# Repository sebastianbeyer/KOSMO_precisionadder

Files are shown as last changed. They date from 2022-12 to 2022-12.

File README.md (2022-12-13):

Precision adder based on [Doepfer A185-2](https://doepfer.de/a1852.htm) in KOSMO format.

You can use precision opamps, but I found that simple TL074 also work.
I could not get the 1V reference voltage to be exactly 1V, maybe my regulator was not great or my resitors were a bit off. 
I would suggest to use not 100 ohms for that, but maybe 500? 

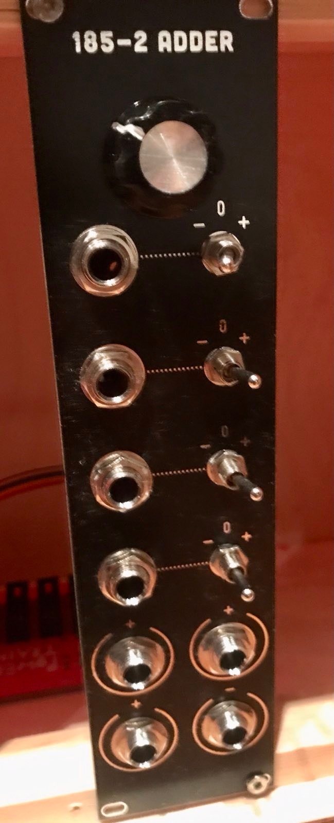
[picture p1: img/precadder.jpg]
Picture of module in case


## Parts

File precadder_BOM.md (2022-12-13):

# precadder.kicad_sch BOM

Tue 13 Dec 2022 10:33:28 CET

Generated from schematic by Eeschema 6.0.8-f2edbf62ab~116~ubuntu22.04.1

**Component Count:** 49

| Refs | Qty | Component | Description | Vendor | SKU |
| ----- | --- | ---- | --- | ---- | ---- |
| C1, C2 | 2 | 10u | Polarized capacitor | Tayda |  |
| C3, C4, C5, C6 | 4 | 100n | Unpolarized capacitor |  |  |
| D1, D2 | 2 | 1N5817 | Schottky Barrier Rectifier Diode, DO-41 | Tayda | A-159 |
| J1 | 1 | out_inv | Audio Jack, 2 Poles (Mono / TS), Switched T Pole (Normalling) | Tayda | A-1121 |
| J2 | 1 | Synth_power_2x5 | Pin header 2.54 mm 2x5 | Tayda | A-2939 |
| J3 | 1 | in_1 | Audio Jack, 2 Poles (Mono / TS), Switched T Pole (Normalling) | Tayda | A-1121 |
| J4 | 1 | in_2 | Audio Jack, 2 Poles (Mono / TS), Switched T Pole (Normalling) | Tayda | A-1121 |
| J5 | 1 | in_3 | Audio Jack, 2 Poles (Mono / TS), Switched T Pole (Normalling) | Tayda | A-1121 |
| J6 | 1 | in_4 | Audio Jack, 2 Poles (Mono / TS), Switched T Pole (Normalling) | Tayda | A-1121 |
| J7 | 1 | out_1 | Audio Jack, 2 Poles (Mono / TS), Switched T Pole (Normalling) | Tayda | A-1121 |
| J8 | 1 | out_3 | Audio Jack, 2 Poles (Mono / TS), Switched T Pole (Normalling) | Tayda | A-1121 |
| J9, J10 | 2 | Conn_01x05_Male | Generic connector, single row, 01x05, script generated (kicad-library-utils/schlib/autogen/connector/) |  |  |
| J11, J12 | 2 | Conn_01x05_Female | Generic connector, single row, 01x05, script generated (kicad-library-utils/schlib/autogen/connector/) |  |  |
| J13 | 1 | out_2 | Audio Jack, 2 Poles (Mono / TS), Switched T Pole (Normalling) | Tayda | A-1121 |
| R1 | 1 | 1k | Resistor | Tayda |  |
| R2, R6, R7, R11, R15, R18 | 6 | 100 | Resistor | Tayda |  |
| R3, R8, R9, R10, R12, R16, R17 | 7 | *100k | Resistor | Tayda |  |
| R4 | 1 | 15k | Resistor | Tayda |  |
| R5 | 1 | 10k | Resistor | Tayda |  |
| R13, R14 | 2 | 100k | Resistor | Tayda |  |
| RV1 | 1 | 100 | Trim-potentiometer | https://www.reichelt.de/praezisionspotentiometer-25-gaenge-stehend-100-ohm-64z-100-p2731.html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 | maybe not 100ohm, but more like 500? |
| RV2 | 1 | gain 500 | Trim-potentiometer | Tayda |  |
| RV3 | 1 | 50k A | Potentiometer | Tayda |  |
| SW1, SW2, SW3, SW4 | 4 | SW_SPDT_MSM | Switch, single pole double throw, center OFF position | Tayda | A-3187 |
| U1, U2 | 2 | LT1014 / TL074 | Quad operational amplifier, DIP-14 | Tayda | A-1138 |
| U3 | 1 | TL431LP | Shunt Regulator, TO-92 |  |  |

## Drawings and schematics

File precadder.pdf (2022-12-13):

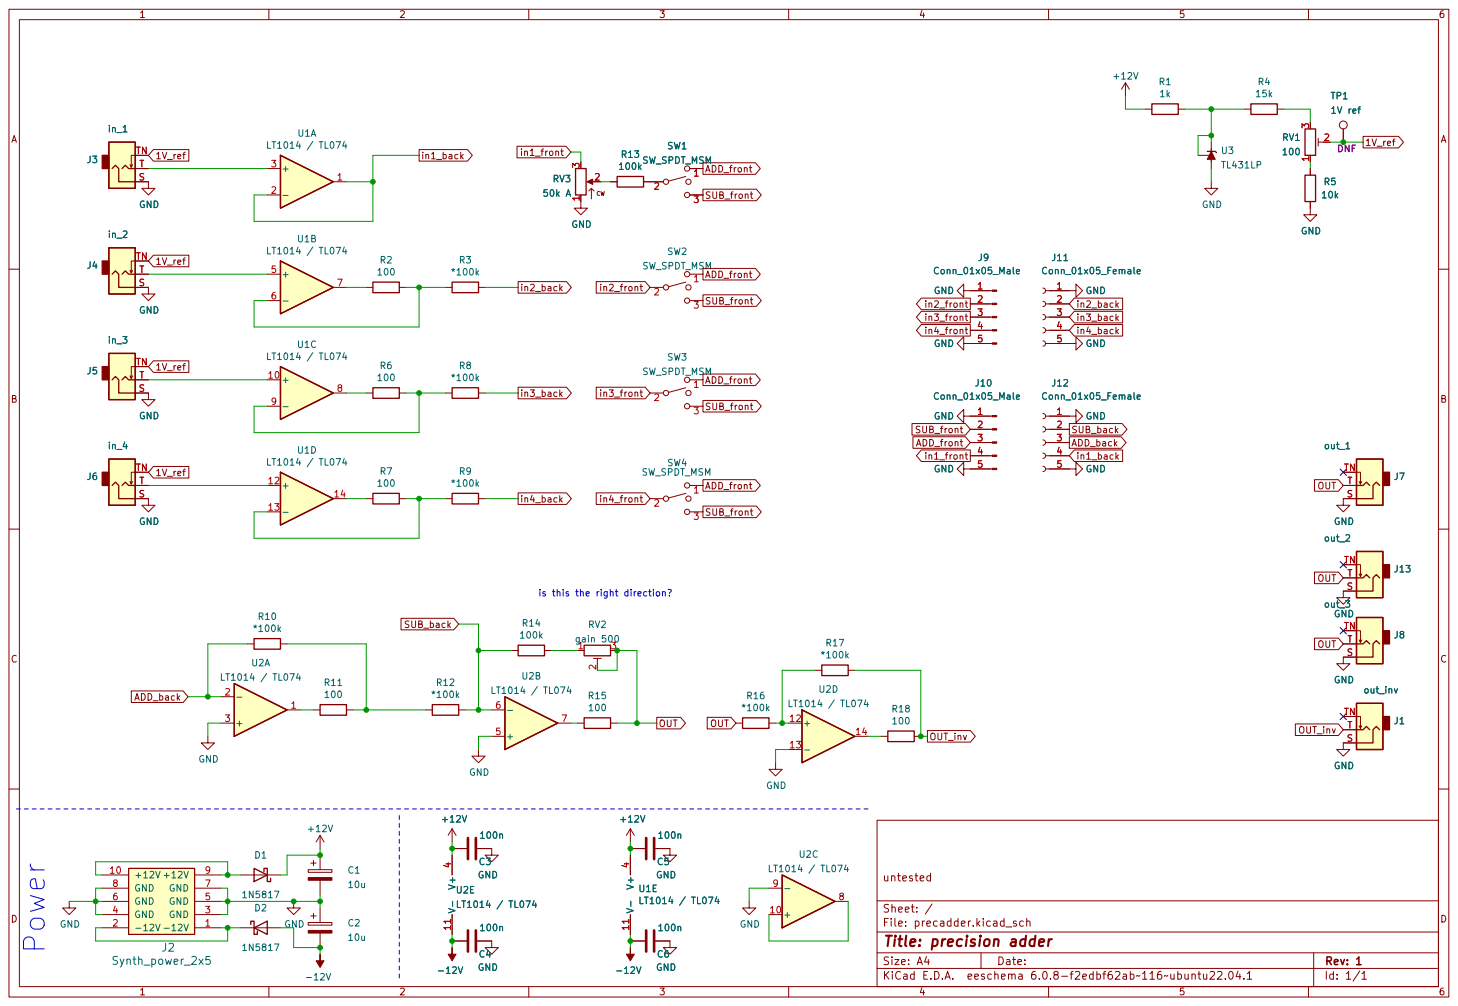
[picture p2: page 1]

is this the right direction? Power

File: precadder.kicad_sch Sheet: / untested

Id: 1/1 Title: precision adder

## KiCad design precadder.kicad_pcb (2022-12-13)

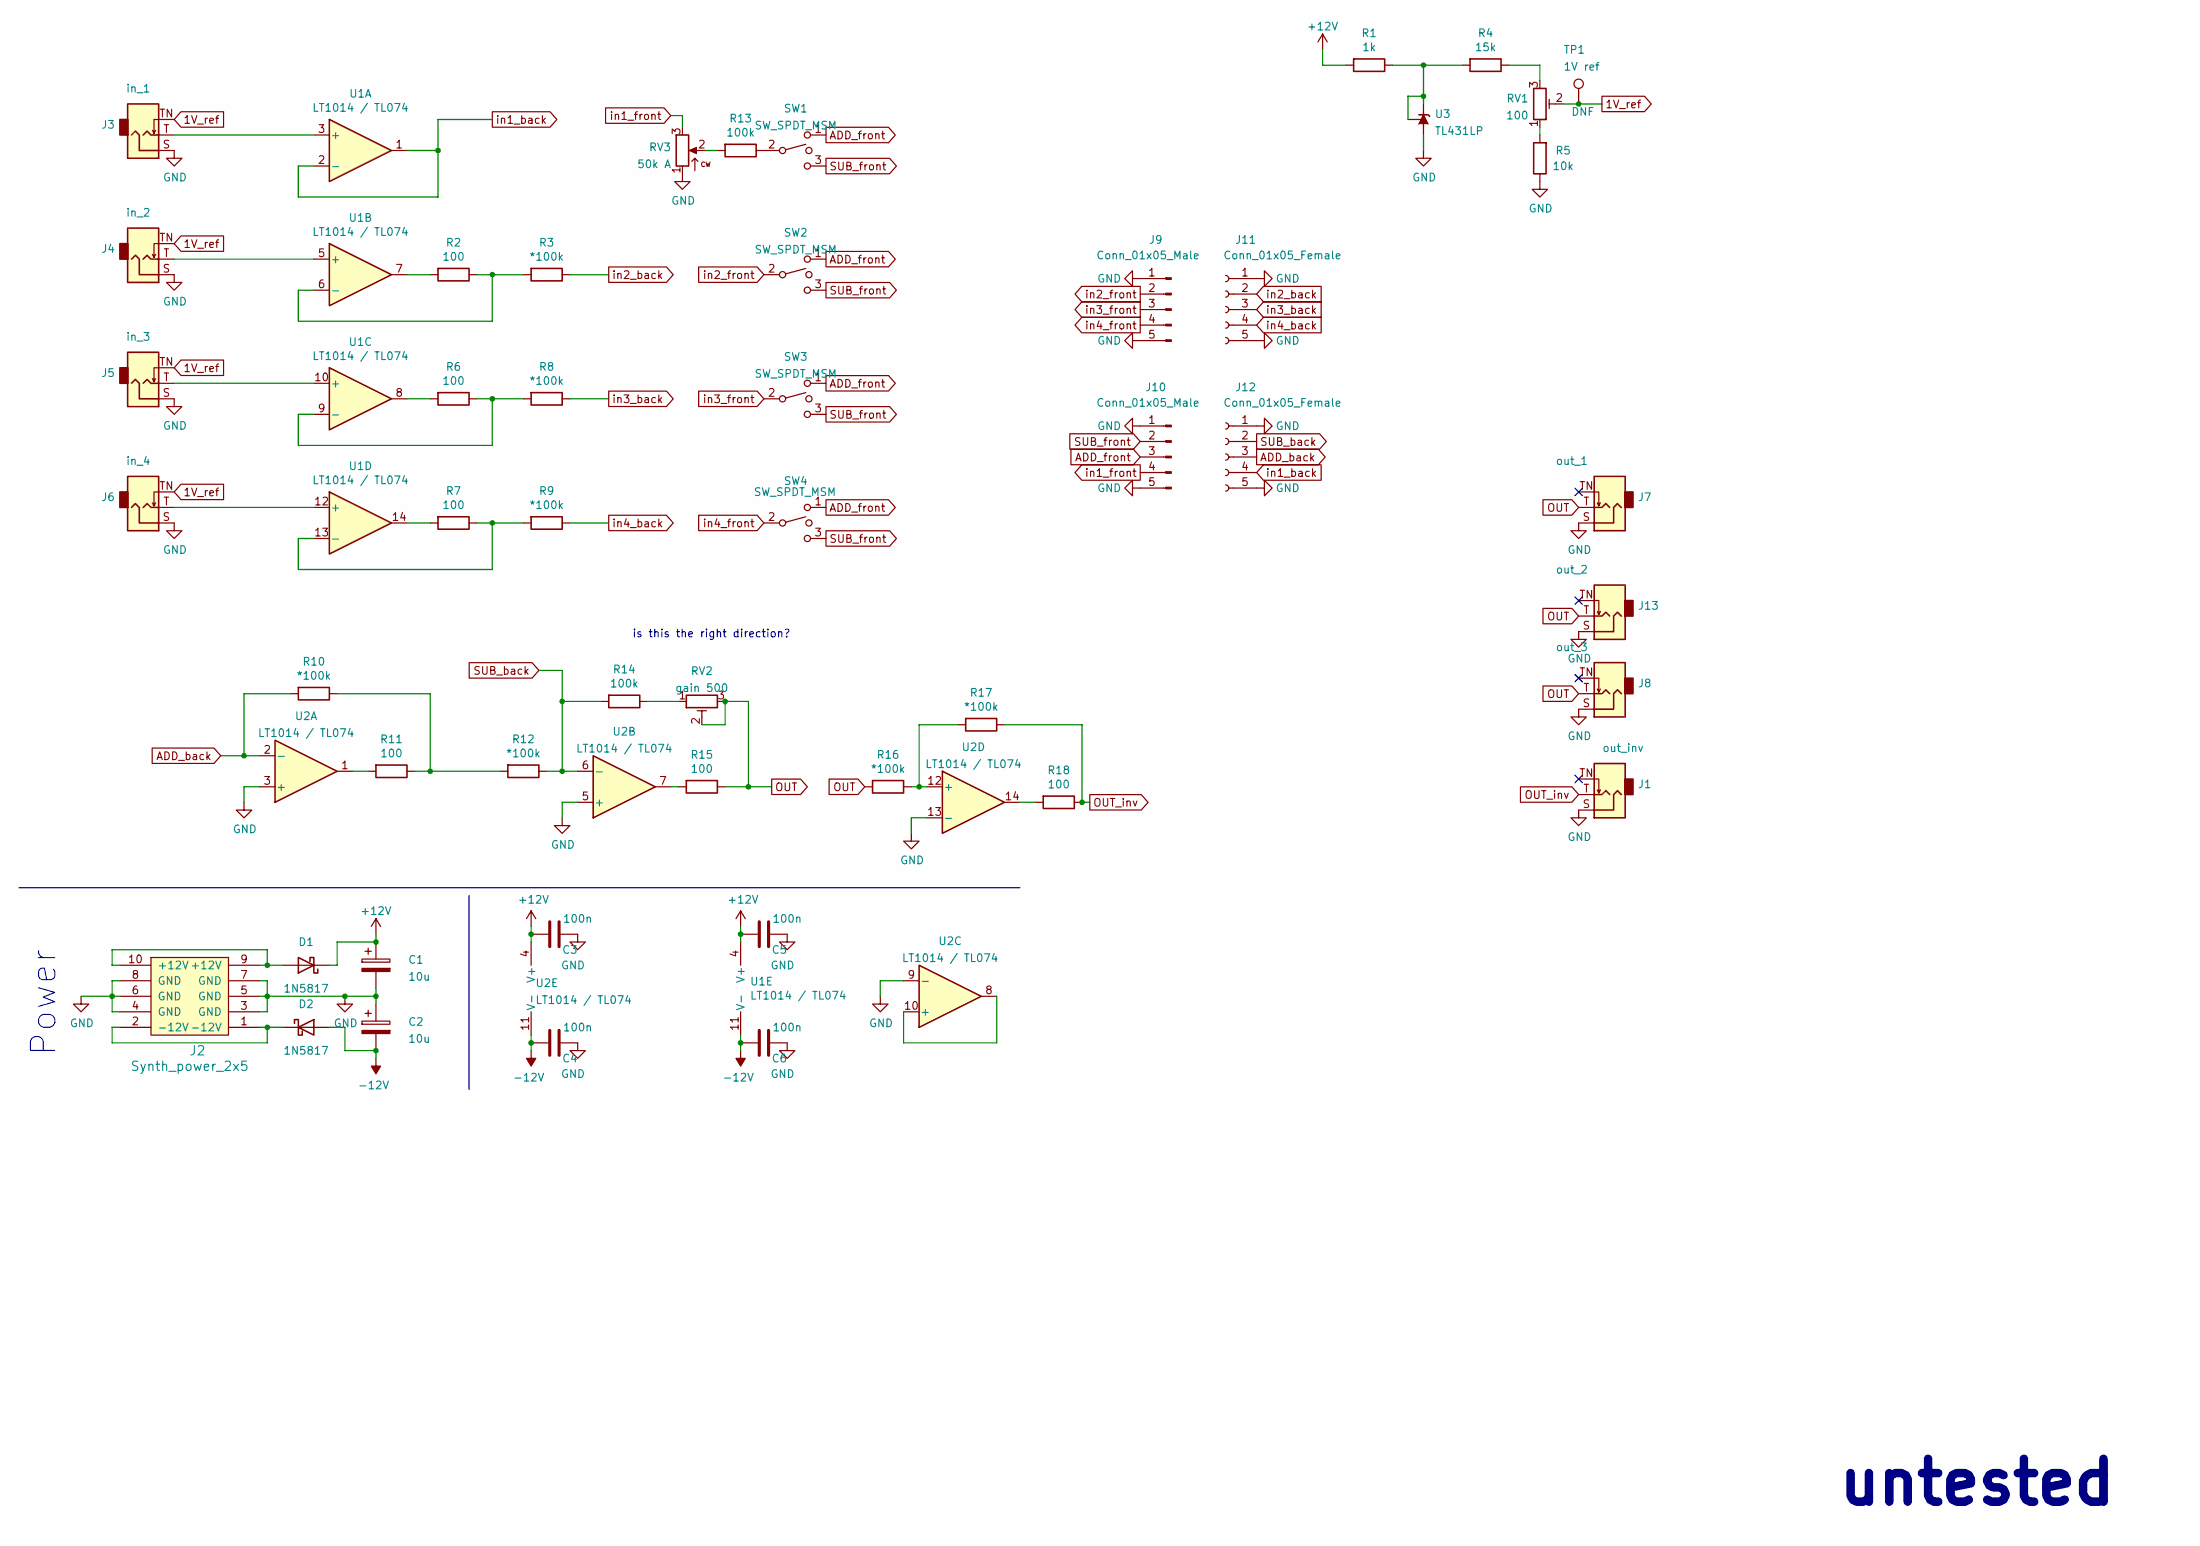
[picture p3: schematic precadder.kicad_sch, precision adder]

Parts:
C1, C2: 10u; CP_Radial_D6.3mm_P2.50mm
C3, C4, C5, C6: 100n; C_Disc_D3.0mm_W1.6mm_P2.50mm
D1, D2: 1N5817; D_DO-41_SOD81_P10.16mm_Horizontal
J1: out_inv; Jack_6.35mm_PJ_629HAN
J2: Synth_power_2x5; Power_Header
J3: in_1; Jack_6.35mm_PJ_629HAN
J4: in_2; Jack_6.35mm_PJ_629HAN
J5: in_3; Jack_6.35mm_PJ_629HAN
J6: in_4; Jack_6.35mm_PJ_629HAN
J7: out_1; Jack_6.35mm_PJ_629HAN
J8: out_3; Jack_6.35mm_PJ_629HAN
J9, J10: Conn_01x05_Male; PinHeader_1x05_P2.54mm_Vertical
J11, J12: Conn_01x05_Female; PinSocket_1x05_P2.54mm_Vertical
J13: out_2; Jack_6.35mm_PJ_629HAN
R1: 1k; R_Axial_DIN0207_L6.3mm_D2.5mm_P10.16mm_Horizontal
R2, R6, R7, R11, R15, R18: 100; R_Axial_DIN0207_L6.3mm_D2.5mm_P10.16mm_Horizontal
R3, R8, R9, R10, R12, R16, R17: *100k; R_Axial_DIN0207_L6.3mm_D2.5mm_P10.16mm_Horizontal
R4: 15k; R_Axial_DIN0207_L6.3mm_D2.5mm_P10.16mm_Horizontal
R5: 10k; R_Axial_DIN0207_L6.3mm_D2.5mm_P10.16mm_Horizontal
R13, R14: 100k; R_Axial_DIN0207_L6.3mm_D2.5mm_P10.16mm_Horizontal
RV1: 100; Potentiometer_Bourns_3296Z_Horizontal
RV2: gain 500; Potentiometer_Bourns_3296Z_Horizontal
RV3: 50k A; Potentiometer_Alpha_RD901F-40-00D_Single_Vertical_centered
SW1, SW2, SW3, SW4: SW_SPDT_MSM; SPDT-toggle-switch-1M-series
TP1: 1V ref; TestPoint_THTPad_D1.5mm_Drill0.7mm
U1, U2: LT1014 / TL074; DIP-14_W7.62mm_Socket_LongPads
U3: TL431LP; TO-92_Inline_Wide

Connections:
1V_ref: J3.TN, J4.TN, J5.TN, J6.TN, RV1.2, TP1.1
+12V: C1.1, C3.2, C5.2, D1.1 (K), R1.2, U1.4 (V+), U2.4 (V+)
-12V: C2.2, C4.2, C6.2, D2.2 (A), U1.11 (V-), U2.11 (V-)
ADD_back: J12.3, R10.2, U2.2 (-)
ADD_front: J10.3, SW1.1, SW2.1, SW3.1, SW4.1
GND: C1.2, C2.1, C3.1, C4.1, C5.1, C6.1, J1.S, J2.3 (GND), J2.4 (GND), J2.5 (GND), J2.6 (GND), J2.7 (GND), J2.8 (GND), J3.S, J4.S, J5.S, J6.S, J7.S, J8.S, J9.1, J9.5, J10.1, J10.5, J11.1, J11.5, J12.1, J12.5, J13.S, R5.1, RV3.1, U2.3 (+), U2.5 (+), U2.9 (-), U2.13 (-), U3.2 (A)
unnamed: D1.2 (A), J2.9 (+12V), J2.10 (+12V)
unnamed: D2.1 (K), J2.1 (-12V), J2.2 (-12V)
unnamed: J3.T, U1.3 (+)
unnamed: J4.T, U1.5 (+)
unnamed: J5.T, U1.10 (+)
unnamed: J6.T, U1.12 (+)
unnamed: R1.1, R4.2, U3.1 (REF), U3.3 (K)
unnamed: R2.1, R3.2, U1.6 (-)
unnamed: R2.2, U1.7
unnamed: R4.1, RV1.3
unnamed: R5.2, RV1.1
unnamed: R6.1, R8.2, U1.9 (-)
unnamed: R6.2, U1.8
unnamed: R7.1, R9.2, U1.13 (-)
unnamed: R7.2, U1.14
unnamed: R10.1, R11.1, R12.2
unnamed: R11.2, U2.1
unnamed: R13.1, SW1.2
unnamed: R13.2, RV3.2
unnamed: R14.1, RV2.1
unnamed: R15.2, U2.7
unnamed: R16.1, R17.2, U2.12 (+)
unnamed: R18.2, U2.14
unnamed: U2.8, U2.10 (+)
OUT: J7.T, J8.T, J13.T, R15.1, R16.2, RV2.2, RV2.3
OUT_inv: J1.T, R17.1, R18.1
SUB_back: J12.2, R12.1, R14.2, U2.6 (-)
SUB_front: J10.2, SW1.3, SW2.3, SW3.3, SW4.3
in1_back: J12.4, U1.1, U1.2 (-)
in1_front: J10.4, RV3.3
in2_back: J11.2, R3.1
in2_front: J9.2, SW2.2
in3_back: J11.3, R8.1
in3_front: J9.3, SW3.2
in4_back: J11.4, R9.1
in4_front: J9.4, SW4.2

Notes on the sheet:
untested
is this the right direction?
Power

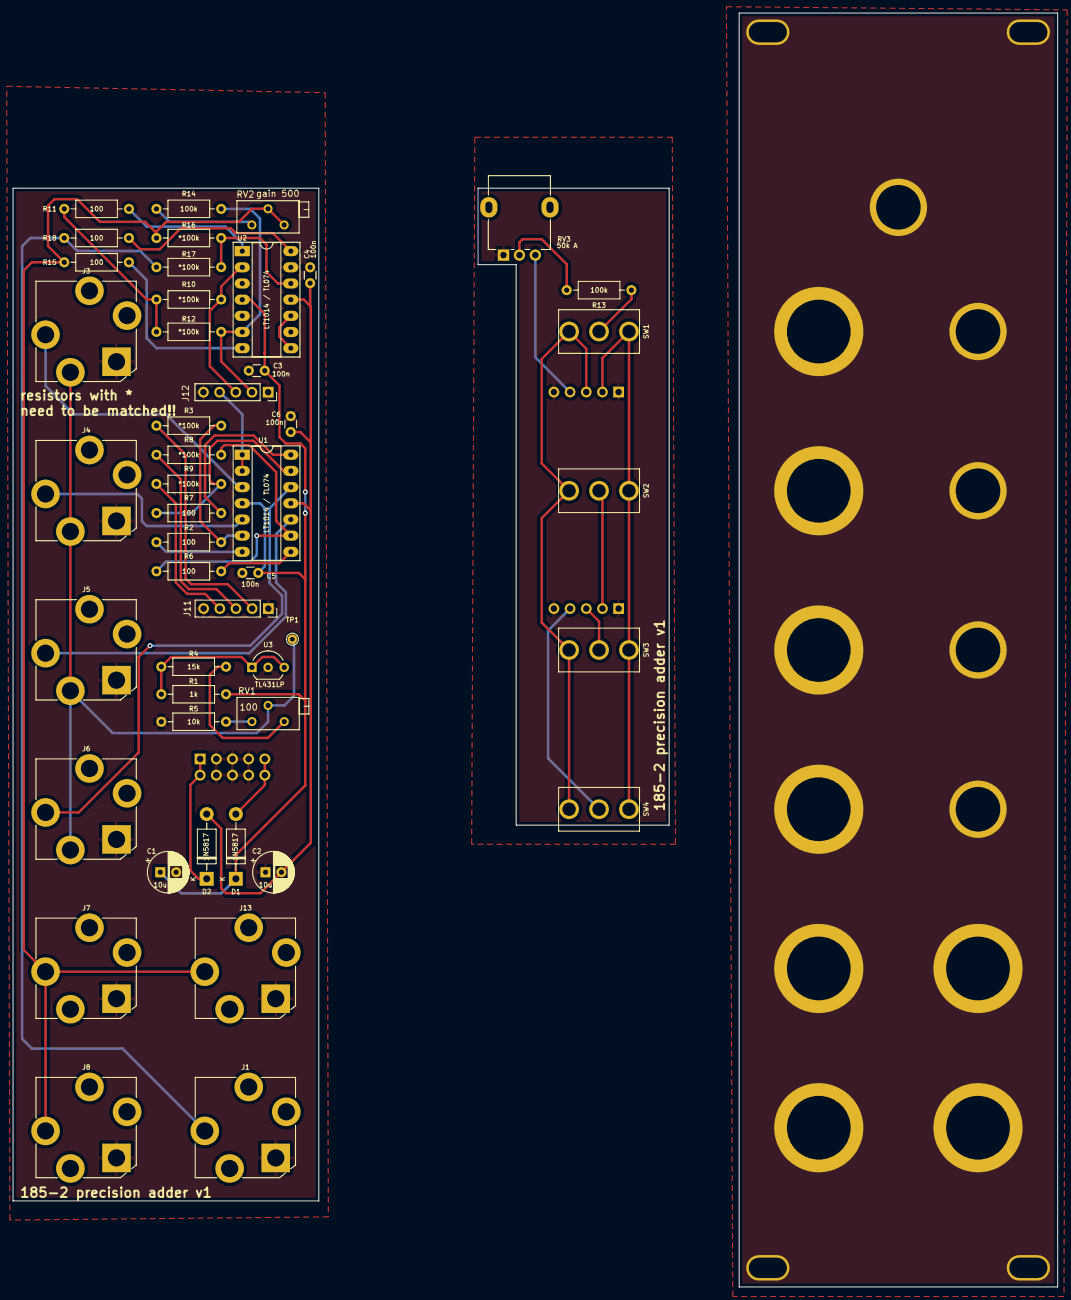
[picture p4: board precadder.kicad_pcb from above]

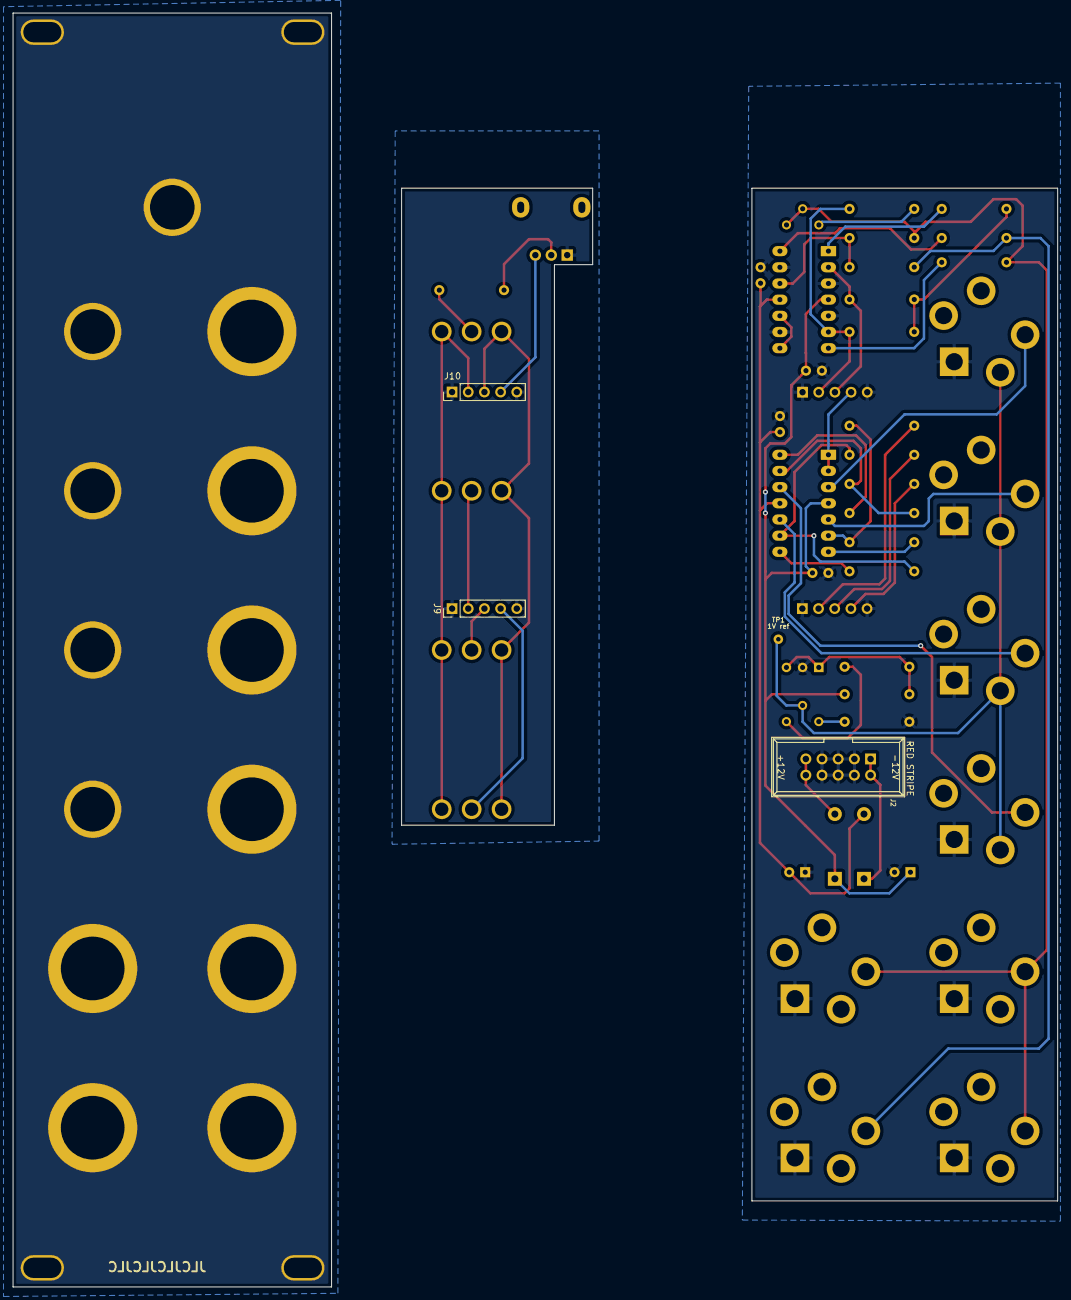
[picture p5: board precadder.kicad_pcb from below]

Board: 2 copper layers, 164.0 x 200.0 mm, 50 parts (3 on the bottom side), 42 nets.
